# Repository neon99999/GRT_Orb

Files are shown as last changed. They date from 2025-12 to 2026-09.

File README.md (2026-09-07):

# The ORB ESP32 sACN IRGB

## For Lighting Operator

### Eos setup (Element or any Eos-family)

**Unicast (preferred, Eos v3.2+)**

1. Set the console NIC to static IP `10.10.50.2` • Mask `255.255.255.0` • Gateway `10.10.50.1`
2. Settings → sACN → enable on that NIC
3. Patch → Protocols → sACN → Per-Universe Overrides
4. Add a unicast target using the ORB IP

**Multicast (older Eos)**

1. This unit can operate in multicast if configured
2. Enable sACN multicast for the selected universe in Eos

---

## Channel map (per configured universe)

> The universe, start address and pixel count are all configurable in the ORB web interface.

### Per-pixel IRGB mode

* **Start address** = Global Intensity
* **Following channels** = Per-pixel RGB in order
* Pixel 1 maps to the **second physical LED**

Example layout shown for clarity only:

* Intensity
* P1 R G B
* P2 R G B
* …
* PN R G B

### Broadcast override (optional)

* Immediately follows the per-pixel block
* Three channels: R G B
* If any channel is >0, the entire strip takes that RGB color scaled by the global intensity

---

## Reserved always-on pixel

* The **first physical LED** is reserved by firmware
* It is always on at a very low level
* It is **not addressable** from DMX
* Purpose:

  * Helps keep USB power banks awake
  * Provides a simple powered-state indicator
  * Intended to be taped over

Pixel count configured in the web interface refers only to **DMX-addressable pixels**.

For example, if there are 24 physical LEDs and the first is reserved, configure 23 DMX-addressable pixels.

---

## Web interface

The ORB includes a built-in configuration UI.

### Access

* `http://10.10.50.201`
* or `http://orb.local` if mDNS is available

### Configurable parameters (live)

Changes apply immediately and persist across reboots.

* sACN universe
* DMX start address
* Run mode

  * 4-channel IRGB
  * Per-pixel IRGB
* DMX-addressable pixel count
* Brightness cap
* Unicast enable or disable

Changing the pixel count safely reinitializes the LED driver without rebooting.

---

## Technical wiring

### Hardware

* ESP32 dev board
* WS2812B or NeoPixel-compatible LEDs (5 V)
* 330 Ω resistor on DIN
* 1000 µF capacitor across +5 V and GND at the strip
* Optional level shifter for long data runs
* Power: 5 V USB-C supply or bank capable of 2–3 A

**Mirror mode**: split the data line after the resistor to drive two identical strips. Each strip requires its own 1000 µF capacitor. Power is star-wired.

---

## Network

### Required network settings

The ORB firmware expects the following network configuration:

* Wi-Fi SSID: `ORB`
* Wi-Fi password: configured in firmware and on the router
* Router LAN IP: `10.10.50.1`
* Subnet mask: `255.255.255.0`
* ORB static IP: `10.10.50.201`
* ORB gateway: `10.10.50.1`
* ORB DNS: `10.10.50.1`

The router does not require an internet connection.

---

## Replacement router setup

Almost any standard Wi-Fi router or travel router can be used as long as it supports a 2.4 GHz Wi-Fi network and allows its LAN address to be changed.

### 1. Connect to the router

* Power on the router
* Connect a laptop using Ethernet or the router's default Wi-Fi network
* Open the router's administration page

The default address and login procedure vary by manufacturer. Check the router label or manual if necessary.

### 2. Configure the LAN

Set:

* Router IP: `10.10.50.1`
* Subnet mask: `255.255.255.0`

Save the settings.

The router may reboot. Afterward, reconnect using:

`http://10.10.50.1`

### 3. Configure DHCP

Set the DHCP range to something similar to:

* Start: `10.10.50.100`
* End: `10.10.50.150`

Do not include `10.10.50.201` in the DHCP pool because that address is reserved for the ORB.

Also keep `10.10.50.2` outside the DHCP pool if it will be used as the lighting console address.

### 4. Configure Wi-Fi

Configure the **2.4 GHz** network with:

* SSID: `ORB`
* Password: must match `WIFI_PASSWORD` in the ORB firmware
* Security: WPA2-Personal / WPA2-PSK AES
* Channel width: 20 MHz
* Channel: 1, 6 or 11
* SSID broadcast: enabled

The SSID is case-sensitive and must be exactly:

`ORB`

### 5. 5 GHz settings

5 GHz can remain enabled for other devices, but the ORB requires a compatible 2.4 GHz network.

If the router combines 2.4 GHz and 5 GHz under one SSID and the ORB has connection problems, separate the bands and use `ORB` for the 2.4 GHz network.

### 6. Connect the ORB

After configuring the router:

1. Power-cycle the ORB
2. Allow several seconds for Wi-Fi connection
3. Connect a laptop to the `ORB` network
4. Open:

`http://10.10.50.201`

If the web interface loads, the ORB is connected correctly.

You can also test from a computer with:

```text
ping 10.10.50.201
```

### 7. Connect an Eos console

Connect the console Ethernet port to a **LAN** port on the router.

Suggested console network settings:

* IP: `10.10.50.2`
* Subnet mask: `255.255.255.0`
* Gateway: `10.10.50.1`

Do not connect the console to the router's WAN or Internet port.

### 8. Configure the ORB

Open the ORB web interface and configure:

* sACN universe
* DMX start address
* pixel count
* operating mode
* brightness cap
* unicast or multicast

DMX addressing does not need to be configured in the router.

---

## TouchDesigner testing

* DMX Out CHOP → Interface sACN
* Match the universe and addressing shown in the web UI
* Unicast to the ORB IP or use multicast
* Feed enough channels to cover intensity, pixels and optional broadcast
* Recommended rate ≤ 44 Hz

---

## Build

* PlatformIO using an ESP32 target
* Libraries:

  * Adafruit NeoPixel
  * ESPAsyncE131
  * ESPAsyncWebServer
  * AsyncTCP
* Upload firmware
* Open Serial at 115200 to view boot status and IP

---

## Power notes

* Each RGB LED can draw up to ~60 mA at full white
* Brightness cap limits peak current
* Do not power LEDs through the ESP32 Vin trace
* Keep 5 V and GND short and thick
* Always place the capacitor at the LED pads

---

## Troubleshooting

* No web interface: confirm the device is connected to the `ORB` 2.4 GHz network
* Cannot ping the ORB: confirm the router LAN is `10.10.50.1/24`
* No DMX output: confirm universe and addressing in the web interface
* Wrong colors: verify pixel color order in firmware
* Flicker or brownout: shorten power leads, confirm voltage at the strip and lower brightness cap
* Power bank sleeping: confirm the reserved always-on pixel is illuminated
* RF instability: use unicast, 20 MHz channel width and a fixed Wi-Fi channel
* ORB will not join Wi-Fi: confirm the SSID is exactly `ORB`, verify the password matches the firmware and confirm WPA2 is enabled

---

## Quick reference

* Wi-Fi SSID: `ORB`
* Router IP: `10.10.50.1`
* ORB IP: `10.10.50.201`
* Console IP: `10.10.50.2`
* Universe: configurable via web UI
* Start address: configurable via web UI
* Pixel count: configurable via web UI
* First physical LED: reserved, always on
* Configuration UI: `http://10.10.50.201` or `http://orb.local`

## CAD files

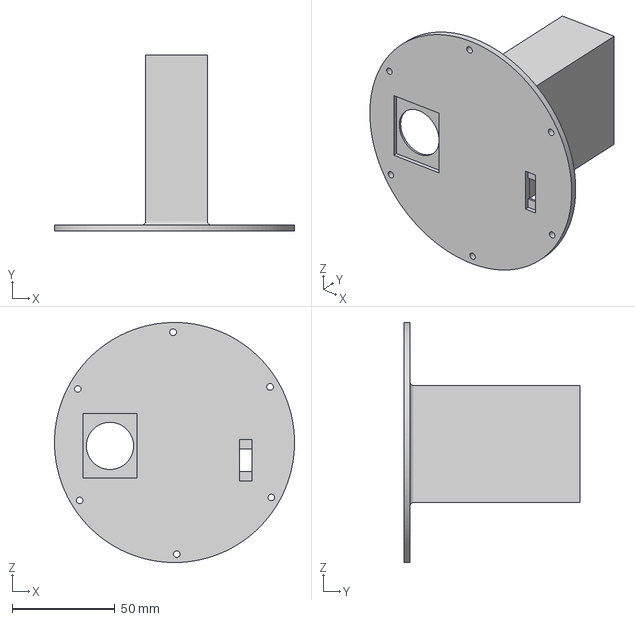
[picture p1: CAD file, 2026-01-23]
3D Print Files/GRT- ORB_01.3mf
117.0 x 86.0 x 117.0 mm

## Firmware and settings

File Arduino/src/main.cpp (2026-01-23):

// main.cpp
#include <Arduino.h>
#include <WiFi.h>
#include <esp_task_wdt.h>

#include "config.h"
#include "wifi_mgr.h"
#include "e131_mgr.h"
#include "dmx_map.h"
#include "leds.h"

#include "web_portal.h"

// WDT and heartbeat
constexpr int WDT_TIMEOUT_S = 5;
constexpr uint32_t HEARTBEAT_MS = 5000;

// stats
static uint8_t prevSeq = 0;
static uint32_t pktCount = 0;
static uint32_t lossCount = 0;
static uint32_t hbStartMs = 0;
static bool wasWifiUp = false;

// buffers
static uint8_t pixBuf[MAX_PIXELS * 3];
static uint8_t dmxBuf[512];

void setup()
{
  Serial.begin(115200);
  delay(200);
  Serial.println();
  Serial.println("=== Boot ===");

  ledsInit();
  ledsSetBrightnessCap(DEFAULT_BRIGHTNESS_CAP);

  wifiInit();
  ledsShowIPOnce(wifiIP());

  webPortalBegin(); // start the web UI (http://<esp-ip>/)

  e131Init();

  // start dark for DMX-controlled pixels, reserved pixel stays on
  ledsWriteAll(0, 0, 0, 0, 0);

  esp_task_wdt_init(WDT_TIMEOUT_S, true);
  esp_task_wdt_add(NULL);

  hbStartMs = millis();
}

void loop()
{
  esp_task_wdt_reset();
  wifiEnsure();

  if (WiFi.status() == WL_CONNECTED && !wasWifiUp)
  {
    e131Init();
    Serial.println("E131 reinit after WiFi reconnect");
  }
  wasWifiUp = (WiFi.status() == WL_CONNECTED);

  uint16_t dlen = 0;
  uint8_t seq = 0;

  while (e131PollRaw(dmxBuf, dlen, seq))
  {
    // stats
    pktCount++;
    if (pktCount > 1)
    {
      uint8_t expect = uint8_t(prevSeq + 1);
      if (seq != expect)
        lossCount++;
    }
    prevSeq = seq;

    if (START_ADDR < 1 || START_ADDR > 512)
      continue;

    const uint16_t base = START_ADDR - 1; // 0-based
    uint8_t gi = dmxBuf[base];

    if (RUN_MODE == MODE_4CH)
    {
      // I,R,G,B at START_ADDR..+3
      uint8_t r = 0, g = 0, b = 0;
      if (base + 3 < 512)
      {
        r = dmxBuf[base + 1];
        g = dmxBuf[base + 2];
        b = dmxBuf[base + 3];
      }

      ledsWriteAll(r, g, b, 0, gi);
    }
    else
    {
      // MODE_PERPIXEL: map per-pixel block starting at START+1
      bool useBroadcast = false;
      uint8_t br = 0, bg = 0, bb = 0;

      DmxFrameView fv{dmxBuf, 512, uint16_t(base)};
      if (dmxMap_PerPixelRGB_GlobalI(fv, pixBuf, NUM_PIXELS, gi, useBroadcast, br, bg, bb))
      {
        if (useBroadcast)
          ledsWriteAll(br, bg, bb, 0, gi);
        else
          ledsWriteStripRGB(pixBuf, NUM_PIXELS, gi);
      }
    }
  }

  // heartbeat
  if (millis() - hbStartMs >= HEARTBEAT_MS)
  {
    uint32_t elapsed = millis() - hbStartMs;
    float pps = elapsed ? (1000.0f * pktCount / elapsed) : 0.0f;

    Serial.print("U");
    Serial.print(E131_UNIVERSE);
    Serial.print(" pps ");
    Serial.print(pps, 1);
    Serial.print(" loss ");
    Serial.print(lossCount);
    Serial.print(" RSSI ");
    Serial.print(WiFi.RSSI());
    Serial.print(" dBm heap ");
    Serial.println(ESP.getFreeHeap());

    pktCount = 0;
    lossCount = 0;
    hbStartMs = millis();
  }
}

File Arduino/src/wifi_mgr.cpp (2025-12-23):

#include "wifi_mgr.h"
#include "config.h"

static bool ledState = false;
static uint32_t nextReconnectMs = 0;
static uint32_t backoffMs = 1000; // start 1 s, max 30 s

static void onWiFiEvent(WiFiEvent_t e)
{
  Serial.print("WiFi evt ");
  Serial.println((int)e);
}

void wifiPrintStatus()
{
  Serial.println();
  Serial.println("=== WiFi ===");
  Serial.print("SSID: ");
  Serial.println(WIFI_SSID);
  Serial.print("IP:   ");
  Serial.println(WiFi.localIP());
  Serial.print("GW:   ");
  Serial.println(WiFi.gatewayIP());
  Serial.print("RSSI: ");
  Serial.print(WiFi.RSSI());
  Serial.println(" dBm");
  Serial.print("MAC:  ");
  Serial.println(WiFi.macAddress());
  Serial.println("===========");
}

void wifiInit()
{
  pinMode(STATUS_LED, OUTPUT);
  WiFi.onEvent(onWiFiEvent);
  WiFi.mode(WIFI_STA);
  WiFi.persistent(false);
  WiFi.setSleep(false);
  if (USE_STATIC_IP)
    WiFi.config(STATIC_IP, STATIC_GW, STATIC_SN, STATIC_DNS);
  WiFi.begin(WIFI_SSID, WIFI_PASSWORD);

  Serial.println();
  Serial.println("WiFi connecting");
  while (WiFi.status() != WL_CONNECTED)
  {
    ledState = !ledState;
    digitalWrite(STATUS_LED, ledState);
    Serial.print(".");
    delay(300);
  }
  digitalWrite(STATUS_LED, HIGH);
  Serial.println("\nWiFi connected");
  wifiPrintStatus();
  backoffMs = 1000;
  nextReconnectMs = 0;
}

void wifiEnsure()
{
  if (WiFi.status() == WL_CONNECTED)
    return;

  uint32_t now = millis();
  if (now < nextReconnectMs)
    return;

  Serial.println("WiFi lost, reconnecting");
  WiFi.disconnect(true);
  WiFi.mode(WIFI_STA);
  WiFi.persistent(false);
  WiFi.setSleep(false);
  if (USE_STATIC_IP)
    WiFi.config(STATIC_IP, STATIC_GW, STATIC_SN, STATIC_DNS);
  WiFi.begin(WIFI_SSID, WIFI_PASSWORD);

  uint32_t t0 = millis();
  while (WiFi.status() != WL_CONNECTED && millis() - t0 < 2000)
  {
    ledState = !ledState;
    digitalWrite(STATUS_LED, ledState);
    delay(200);
  }
  if (WiFi.status() == WL_CONNECTED)
  {
    digitalWrite(STATUS_LED, HIGH);
    Serial.println("WiFi reconnected");
    wifiPrintStatus();
    backoffMs = 1000;
    nextReconnectMs = 0;
  }
  else
  {
    backoffMs = min(backoffMs * 2, (uint32_t)30000);
    nextReconnectMs = now + backoffMs;
    Serial.print("Retry in ");
    Serial.print(backoffMs);
    Serial.println(" ms");
  }
}

IPAddress wifiIP() { return WiFi.localIP(); }

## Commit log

2025-08-27 Updated to new board details
2025-12-23 Updated to fix issue of power cutting when no signal sent
    [main.cpp, wifi_mgr.cpp]
2026-01-16 Updated to V2 with led strip
    Updated the max brightness, fixed the keep alive feature.
2026-01-23 ORB v2.1 – reserved always-on pixel + simplified runtime (#1)
    * Updated to add webportal working well
    * Update to remove the timeout
    Now has single led that stays on at low power all the time.
    Rest of pixels were shifted.
    Note if there are 25 pixels, set pix count to 24
    * Updates to readme and 3d file
    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
    [GRT- ORB_01.3mf]
